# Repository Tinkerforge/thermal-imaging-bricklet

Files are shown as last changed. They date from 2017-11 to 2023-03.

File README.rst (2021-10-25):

Thermal Imaging Bricklet
========================

This repository contains the firmware source code and the hardware design
files. The documentation generator configs can be found at
https://github.com/Tinkerforge/generators

Repository Content
------------------

software/:
 * examples/: Examples for all supported languages
 * build/: Compiled files
 * src/: Source code of firmware
 * Makefile: Makefile to build project

hardware/:
 * Contains KiCad project files and additionally schematics as PDF

datasheets/:
 * Contains datasheets for sensors and complex ICs that are used

Hardware
--------

The hardware is designed with the open source EDA Suite KiCad
(http://www.kicad.org). Before you are able to open the files,
you have to install the Tinkerforge kicad-libraries
(https://github.com/Tinkerforge/kicad-libraries). You can either clone
them directly in hardware/ or clone them in a separate folder and
symlink them into hardware/
(ln -s kicad_path/kicad-libraries project_path/hardware). After that you
can open the .pro file in hardware/ with KiCad and from there view and
modify the schematics and the PCB layout.

Software
--------

If you want to do your own Brick/Bricklet firmware development we highly
recommend that you use our build environment setup script and read the
tutorial (https://www.tinkerforge.com/en/doc/Tutorials/Tutorial_Build_Environment/Tutorial.html).

To compile the C code we recommend you to install the newest GNU Arm Embedded
Toolchain (https://launchpad.net/gcc-arm-embedded/+download).
You also need to install bricklib2 (https://github.com/Tinkerforge/bricklib2).

You can either clone it directly in software/src/ or clone it in a
separate folder and symlink it into software/src/
(ln -s bricklib_path/bricklib2 project_path/software/src/). Finally make sure to
have CMake installed (http://www.cmake.org/cmake/resources/software.html).

After that you can build the firmware by invoking make in software/.
The firmware (.zbin) can then be found in software/build/ and uploaded
with brickv (click button "Flashing" on start screen).

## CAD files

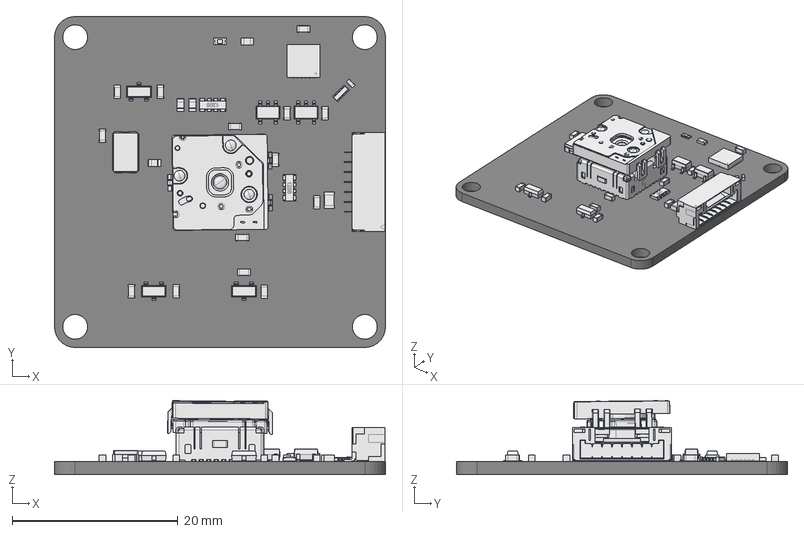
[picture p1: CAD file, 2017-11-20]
hardware/thermal-imaging.FCStd
40.0 x 40.0 x 8.95 mm
Pcb
C_0402_
C_0805_
BrickletConn_7pin_
SOT23_
SOT23_001
SOT-23-5_
SOT-23-5_001
R_4x0603_
R_4x0603_001
R_0603_
R_0603_001
R_0603_002
R_0603_003
C_0603_
C_0603_001
C_0603_002
C_0603_003
C_0603_004
C_0603_005
C_0603_006
C_0603_007
C_0603_008
C_0603_009
C_0603_010
C_0603_011
C_0603_012
QFN-24_4x4mm_Pitch0.5mm_
C_0603_013
SOT23_002
D_0603_blue_
FLIR-500-0763-01_Module+Base_

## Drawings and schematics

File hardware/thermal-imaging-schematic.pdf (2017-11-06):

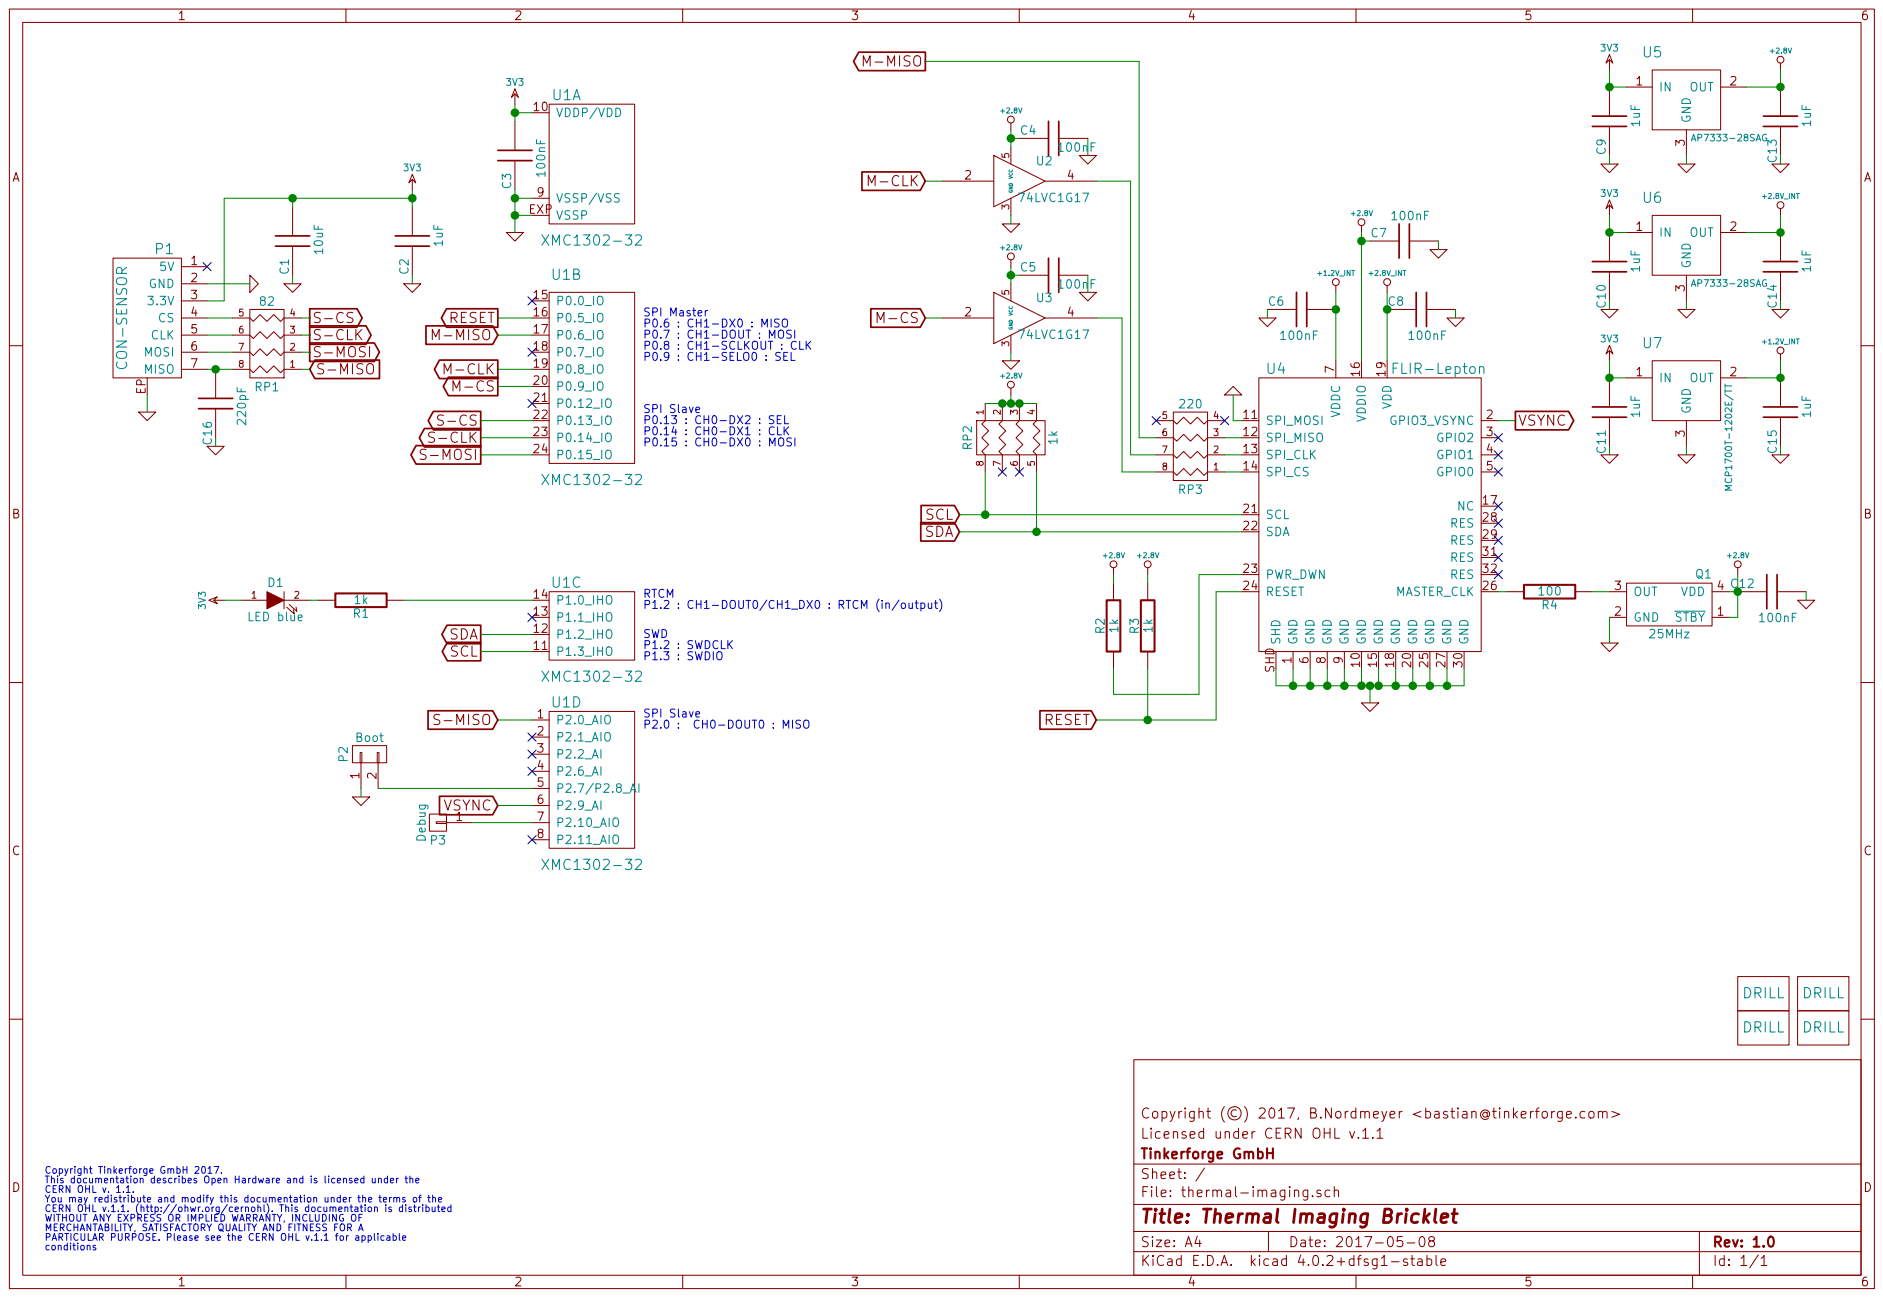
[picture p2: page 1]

P0.7 : CH1-DOUT : MOSI P0.8 : CH1-SCLKOUT : CLK
P0.9 : CH1-SELO0 : SEL SPI Slave P0.13 : CH0-DX2 : SEL P0.14 : CH0-DX1 : CLK

9 GND 10 GND 20 GND 30 SPI_MOSI 11 SCL 21 RES 31 SPI_MISO 12 SDA 22 RES 32 SPI_CLK 13 PWR_DWN 23 SPI_CS 14 RESET 24 GND 15 GND 25 VDDIO 16 MASTER_CLK 26 NC 17 GND 27 GND 18 RES 28 VDD 19 RES 29 SHD SHD U4 FLIR-Lepton

P1.2 : CH1-DOUT0/CH1_DX0 : RTCM (in/output) SPI Slave P2.0 : CH0-DOUT0 : MISO

Licensed under CERN OHL v.1.1 Copyright (©) 2017, B.Nordmeyer <bastian@tinkerforge.com>

File: thermal-imaging.sch Sheet: / Tinkerforge GmbH

Copyright Tinkerforge GmbH 2017. This documentation describes Open Hardware and is licensed under the CERN OHL v. 1.1. You may redistribute and modify this documentation under the terms of the CERN OHL v.1.1. (http://ohwr.org/cernohl). This documentation is distributed WITHOUT ANY EXPRESS OR IMPLIED WARRANTY, INCLUDING OF MERCHANTABILITY, SATISFACTORY QUALITY AND FITNESS FOR A

Id: 1/1 Title: Thermal Imaging Bricklet

PARTICULAR PURPOSE. Please see the CERN OHL v.1.1 for applicable

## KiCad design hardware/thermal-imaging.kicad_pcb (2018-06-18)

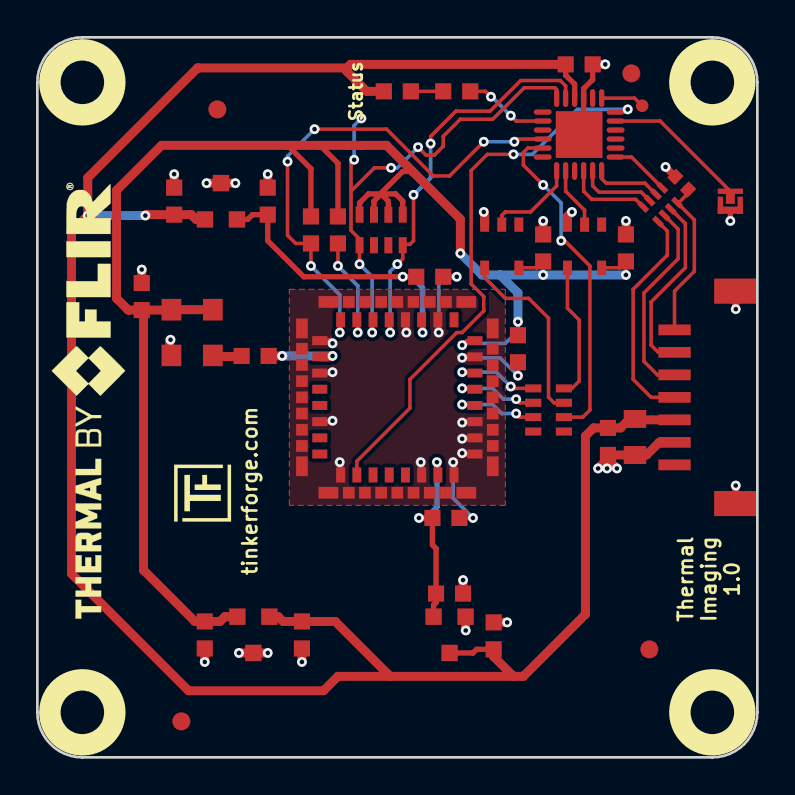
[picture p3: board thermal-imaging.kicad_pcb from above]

Board: 2 copper layers, 40.0 x 40.0 mm, 44 parts (1 on the bottom side), 32 nets.

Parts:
C1: 10uF; C0805
C2, C9, C10, C11, C13, C14, C15: 1uF; C0603F
C3, C4, C5, C6, C7, C8, C12: 100nF; C0603F
C16: 220pF; C0402F
D1: LED blue; D0603F
Fiducial_Mark: VAL**; Fiducial_Mark
Fiducial_Mark#2, Fiducial_Mark#3, Fiducial_Mark#4: VAL**; Fiducial_Mark
P1: CON-SENSOR; CON-SENSOR2
P2: Boot; SolderJumper
P3: Debug; DEBUG_PAD
Q1: 25MHz; CRYSTAL_5032
R1, R2, R3: 1k; R0603F
R4: 100; R0603F
RP1: 82; 4X0402
RP2: 1k; 0603X4
RP3: 220; 0603X4
U1: XMC1302-32; QFN24-4x4mm-0.5mm
U2, U3: 74LVC1G17; SOT23-5
U4: FLIR-Lepton; Lepton_105028
U5, U6: AP7333-28SAG; SOT23-3
U7: MCP1700T-1202E/TT; SOT23-3R
U8, U9, U10, U11: DRILL; DRILL_NP
VAL: CE_5mm

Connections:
3V3: C1.2, C2.2, C3.2, C9.2, C10.2, C11.2, D1.1, P1.3, U1.10, U5.1, U6.1, U7.1
+1.2V_INT: C6.2, C15.2, U4.7, U7.2
+2.8V: C4.1, C5.1, C7.1, C12.1, C13.2, Q1.1, Q1.4, R2.2, R3.2, RP2.1, RP2.2, RP2.3, RP2.4, U2.5, U3.5, U4.16, U5.2
+2.8V_INT: C8.1, C14.2, U4.19, U6.2
GND: C1.1, C2.1, C3.1, C4.2, C5.2, C6.1, C7.2, C8.2, C9.1, C10.1, C11.1, C12.2, C13.1, C14.1, C15.1, C16.1, P1.2, P1.EP, P2.1, Q1.2, U1.9, U1.EXP, U2.3, U3.3, U4.1, U4.6, U4.8, U4.9, U4.10, U4.11, U4.15, U4.18, U4.20, U4.25, U4.27, U4.30, U4.SHD, U5.3, U6.3, U7.3
M-CLK: U1.19, U2.2
M-CS: U1.20, U3.2
M-MISO: RP3.6, U1.17
unnamed: C16.2, P1.7, RP1.8
unnamed: D1.2, R1.2
unnamed: P1.4, RP1.5
unnamed: P1.5, RP1.6
unnamed: P1.6, RP1.7
unnamed: P2.2, U1.5
unnamed: P3.1, U1.7
unnamed: Q1.3, R4.1
unnamed: R1.1, U1.14
unnamed: R2.1, U4.23
unnamed: R4.2, U4.26
unnamed: RP3.1, U4.14
unnamed: RP3.2, U4.13
unnamed: RP3.3, U4.12
unnamed: RP3.7, U2.4
unnamed: RP3.8, U3.4
RESET: R3.1, U1.16, U4.24
S-CLK: RP1.3, U1.23
S-CS: RP1.4, U1.22
S-MISO: RP1.1, U1.1
S-MOSI: RP1.2, U1.24
SCL: RP2.8, U1.11, U4.21
SDA: RP2.5, U1.12, U4.22
VSYNC: U1.6, U4.2

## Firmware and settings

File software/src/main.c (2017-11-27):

/* thermal-imaging-bricklet
 * Copyright (C) 2017 Olaf Lüke <olaf@tinkerforge.com>
 *
 * main.c: Initialization for Thermal Imaging Bricklet
 *
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
 * You should have received a copy of the GNU Lesser General Public
 * License along with this library; if not, write to the
 * Free Software Foundation, Inc., 59 Temple Place - Suite 330,
 * Boston, MA 02111-1307, USA.
 */

#include <stdio.h>
#include <stdbool.h>

#include "configs/config.h"

#include "bricklib2/bootloader/bootloader.h"
#include "bricklib2/hal/system_timer/system_timer.h"
#include "bricklib2/utility/communication_callback.h"
#include "communication.h"
#include "lepton.h"

Lepton lepton;

int main(void) {
	lepton_init(&lepton);

	while(true) {
		bootloader_tick();
		communication_tick();
		lepton_tick(&lepton);
	}
}

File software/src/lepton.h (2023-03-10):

/* thermal-imaging-bricklet
 * Copyright (C) 2017 Olaf Lüke <olaf@tinkerforge.com>
 *
 * lepton.h: Lepton thermal imaging camera module communication
 *
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
 * You should have received a copy of the GNU Lesser General Public
 * License along with this library; if not, write to the
 * Free Software Foundation, Inc., 59 Temple Place - Suite 330,
 * Boston, MA 02111-1307, USA.
 */

#ifndef LEPTON_H
#define LEPTON_H

#include <stdint.h>
#include <stdbool.h>

#define LEPTON_I2C_COMMAND_MODULE_ID_BITMASK       (uint16_t)0x0F00
#define LEPTON_I2C_COMMAND_ID_BITMASK              (uint16_t)0x00FC
#define LEPTON_I2C_COMMAND_TYPE_BITMASK            (uint16_t)0x0003

#define LEPTON_I2C_COMMAND_TYPE_GET                (uint16_t)0x0000
#define LEPTON_I2C_COMMAND_TYPE_SET                (uint16_t)0x0001
#define LEPTON_I2C_COMMAND_TYPE_RUN                (uint16_t)0x0002

#define LEPTON_I2C_STATUS_BUSY_BITMASK             (uint16_t)0x0001
#define LEPTON_I2C_STATUS_BOOT_MODE_BITMASK        (uint16_t)0x0002
#define LEPTON_I2C_STATUS_BOOT_STATUS_BITMASK      (uint16_t)0x0004
#define LEPTON_I2C_STATUS_ERROR_CODE_BITMASK       (uint16_t)0xFF00
#define LEPTON_I2C_STATUS_ERROR_CODE_BITSHIFT      8

#define LEPTON_I2C_REG_BASE_ADDR                   (uint16_t)0x0000
#define LEPTON_I2C_POWER_REG                       (uint16_t)(LEPTON_I2C_REG_BASE_ADDR + 0x0000)
#define LEPTON_I2C_STATUS_REG                      (uint16_t)(LEPTON_I2C_REG_BASE_ADDR + 0x0002)
#define LEPTON_I2C_COMMAND_REG                     (uint16_t)(LEPTON_I2C_REG_BASE_ADDR + 0x0004)
#define LEPTON_I2C_DATA_LENGTH_REG                 (uint16_t)(LEPTON_I2C_REG_BASE_ADDR + 0x0006)
#define LEPTON_I2C_DATA_0_REG                      (uint16_t)(LEPTON_I2C_REG_BASE_ADDR + 0x0008)
#define LEPTON_I2C_DATA_1_REG                      (uint16_t)(LEPTON_I2C_REG_BASE_ADDR + 0x000A)
#define LEPTON_I2C_DATA_2_REG                      (uint16_t)(LEPTON_I2C_REG_BASE_ADDR + 0x000C)
#define LEPTON_I2C_DATA_3_REG                      (uint16_t)(LEPTON_I2C_REG_BASE_ADDR + 0x000E)
#define LEPTON_I2C_DATA_4_REG                      (uint16_t)(LEPTON_I2C_REG_BASE_ADDR + 0x0010)
#define LEPTON_I2C_DATA_5_REG                      (uint16_t)(LEPTON_I2C_REG_BASE_ADDR + 0x0012)
#define LEPTON_I2C_DATA_6_REG                      (uint16_t)(LEPTON_I2C_REG_BASE_ADDR + 0x0014)
#define LEPTON_I2C_DATA_7_REG                      (uint16_t)(LEPTON_I2C_REG_BASE_ADDR + 0x0016)
#define LEPTON_I2C_DATA_8_REG                      (uint16_t)(LEPTON_I2C_REG_BASE_ADDR + 0x0018)
#define LEPTON_I2C_DATA_9_REG                      (uint16_t)(LEPTON_I2C_REG_BASE_ADDR + 0x001A)
#define LEPTON_I2C_DATA_10_REG                     (uint16_t)(LEPTON_I2C_REG_BASE_ADDR + 0x001C)
#define LEPTON_I2C_DATA_11_REG                     (uint16_t)(LEPTON_I2C_REG_BASE_ADDR + 0x001E)
#define LEPTON_I2C_DATA_12_REG                     (uint16_t)(LEPTON_I2C_REG_BASE_ADDR + 0x0020)
#define LEPTON_I2C_DATA_13_REG                     (uint16_t)(LEPTON_I2C_REG_BASE_ADDR + 0x0022)
#define LEPTON_I2C_DATA_14_REG                     (uint16_t)(LEPTON_I2C_REG_BASE_ADDR + 0x0024)
#define LEPTON_I2C_DATA_15_REG                     (uint16_t)(LEPTON_I2C_REG_BASE_ADDR + 0x0026)
#define LEPTON_I2C_DATA_CRC_REG                    (uint16_t)(LEPTON_I2C_REG_BASE_ADDR + 0x0028)

#define LEPTON_I2C_DATA_BUFFER                     (uint16_t)0xF800
#define LEPTON_I2C_DATA_BUFFER_LENGTH              (uint16_t)0x0800

#define LEPTON_AGC_MODULE_BASE                     (uint16_t)0x0100
#define LEPTON_CID_AGC_ENABLE_STATE                (uint16_t)(LEPTON_AGC_MODULE_BASE + 0x0000)
#define LEPTON_CID_AGC_POLICY                      (uint16_t)(LEPTON_AGC_MODULE_BASE + 0x0004)
#define LEPTON_CID_AGC_ROI                         (uint16_t)(LEPTON_AGC_MODULE_BASE + 0x0008)
#define LEPTON_CID_AGC_STATISTICS                  (uint16_t)(LEPTON_AGC_MODULE_BASE + 0x000C)
#define LEPTON_CID_AGC_HISTOGRAM_CLIP_PERCENT      (uint16_t)(LEPTON_AGC_MODULE_BASE + 0x0010)
#define LEPTON_CID_AGC_HISTOGRAM_TAIL_SIZE         (uint16_t)(LEPTON_AGC_MODULE_BASE + 0x0014)
#define LEPTON_CID_AGC_LINEAR_MAX_GAIN             (uint16_t)(LEPTON_AGC_MODULE_BASE + 0x0018)
#define LEPTON_CID_AGC_LINEAR_MIDPOINT             (uint16_t)(LEPTON_AGC_MODULE_BASE + 0x001C)
#define LEPTON_CID_AGC_LINEAR_DAMPENING_FACTOR     (uint16_t)(LEPTON_AGC_MODULE_BASE + 0x0020)
#define LEPTON_CID_AGC_HEQ_DAMPENING_FACTOR        (uint16_t)(LEPTON_AGC_MODULE_BASE + 0x0024)
#define LEPTON_CID_AGC_HEQ_MAX_GAIN                (uint16_t)(LEPTON_AGC_MODULE_BASE + 0x0028)
#define LEPTON_CID_AGC_HEQ_CLIP_LIMIT_HIGH         (uint16_t)(LEPTON_AGC_MODULE_BASE + 0x002C)
#define LEPTON_CID_AGC_HEQ_CLIP_LIMIT_LOW          (uint16_t)(LEPTON_AGC_MODULE_BASE + 0x0030)
#define LEPTON_CID_AGC_HEQ_BIN_EXTENSION           (uint16_t)(LEPTON_AGC_MODULE_BASE + 0x0034)
#define LEPTON_CID_AGC_HEQ_MIDPOINT                (uint16_t)(LEPTON_AGC_MODULE_BASE + 0x0038)
#define LEPTON_CID_AGC_HEQ_EMPTY_COUNTS            (uint16_t)(LEPTON_AGC_MODULE_BASE + 0x003C)
#define LEPTON_CID_AGC_HEQ_NORMALIZATION_FACTOR    (uint16_t)(LEPTON_AGC_MODULE_BASE + 0x0040)
#define LEPTON_CID_AGC_HEQ_SCALE_FACTOR            (uint16_t)(LEPTON_AGC_MODULE_BASE + 0x0044)
#define LEPTON_CID_AGC_CALC_ENABLE_STATE           (uint16_t)(LEPTON_AGC_MODULE_BASE + 0x0048)
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

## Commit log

2017-02-07 basic schematic, first placement
    [thermal-imaging.kicad_pcb, thermal-imaging.sch]
2017-02-08 routing completed
    [thermal-imaging.kicad_pcb, thermal-imaging.sch]
2017-02-08 add description text
    [thermal-imaging.kicad_pcb]
2017-02-24 fix wrong footprint
    [thermal-imaging.kicad_pcb]
2017-03-10 Add initial stub implementation (defines and initialization)
    [cmake_config_custom.txt]
2017-03-14 change pin error note
    [thermal-imaging.sch]
2017-03-20 Add initial packet handling
    This is still WIP, currently it is too slow to read a packet and transfer it through SPI at the same time.
    [lepton.c, lepton.h]
2017-03-20 Use 8MHz SPI clock speed
2017-03-20 Do receive completely in interrupt for 16 bytes at a time
2017-03-21 add vsync pin change hint
    [thermal-imaging.sch]
2017-03-22 Implement grey scale and temperature callbacks
2017-03-22 Add vsync ISR and implement proper reception of 27 frames per second
2017-03-23 fix text orientation
    [thermal-imaging.kicad_pcb]
2017-03-24 Change name from Temperature to Raw and Grey Scale to Image
2017-03-24 Disable SPI/I2C properly if the other one is enabled
2017-03-24 Return from interrupt if interface is not SPI
2017-03-24 Enable config handler after frame is done
2017-03-30 Add crc check function (currently unused)
2017-03-30 Add missing id and crc to telemetry
    [lepton.h]
2017-03-31 Put temperature and status information in same sequence
2017-04-03 Don't use sync signal if transfer is currently still active
2017-04-03 Make sure SPI select pin is high if SPI is not used
2017-04-03 deselect SPI after sync
2017-04-06 change text orientation
    [thermal-imaging.kicad_pcb]
2017-04-06 Change direction around, so that by default the Bricklets works as a normal camera, not as a selfie camera
2017-05-08 fix vsync connection, footprints
    [thermal-imaging.kicad_pcb, thermal-imaging.sch]
2017-05-12 fix part texts
    [thermal-imaging.kicad_pcb, thermal-imaging.sch]
2017-05-12 Fix CE logo
    [thermal-imaging.kicad_pcb]
2017-06-02 specify oscillator frequency
    [thermal-imaging.kicad_pcb, thermal-imaging.sch]
2017-08-11 specify filter circuit
    [thermal-imaging.kicad_pcb, thermal-imaging.sch]
2017-08-28 add flir logo
    [thermal-imaging.kicad_pcb, thermal-imaging.sch]
2017-09-19 specify processor type
    [thermal-imaging.kicad_pcb, thermal-imaging.sch]
2017-11-06 Add 3d information (tbc)
    [thermal-imaging.kicad_pcb]
2017-11-06 Add final schematic
2017-11-07 Split status into ffc status and temperature warnings
2017-11-08 Fix temperature warning bug
2017-11-20 Add 3d information (final)
    [thermal-imaging.kicad_pcb]
2017-11-20 Add 3d model (*.step & *.FCStd)
    [thermal-imaging.FCStd]
2017-11-20 Fix path to 3d model of FLIR module
    [thermal-imaging.kicad_pcb]
2017-12-21 Add humidity, air pressure and ambient light support
2017-12-28 Adapt path for Raspberry Pi Demo
2018-02-20 Cleanup KiCad libraries config
    Ensure LibDir=kicad-libraries and LibName1=tinkerforge.
    Remove special library.
2018-06-18 Change capacitor footprint(s) to C0402F
    [thermal-imaging.kicad_pcb, thermal-imaging.sch]
2019-05-28 Move CRC check outside of sync interrupt
    The CRC check sometimes took so long that the SPITFP irq
    would start to transfer zeros and introduce CRC errors in the
    SPI protocol
    [lepton.c, lepton.h]
2019-05-28 Improve SPI IRQ performance
    Use local pointer to save the time for accessing the struct
2019-08-13 Double buffer lepton statistics to prevent statistics tearing
    [lepton.c, lepton.h]
2020-02-05 Don't start new frame read if a manual transfer is ongoing
2020-09-02 uc: Add example driver note.
2021-10-25 Update KiCad link
    https://www.kicad.org/blog/2021/10/Avoid-links-to-former-kicad-domain/
